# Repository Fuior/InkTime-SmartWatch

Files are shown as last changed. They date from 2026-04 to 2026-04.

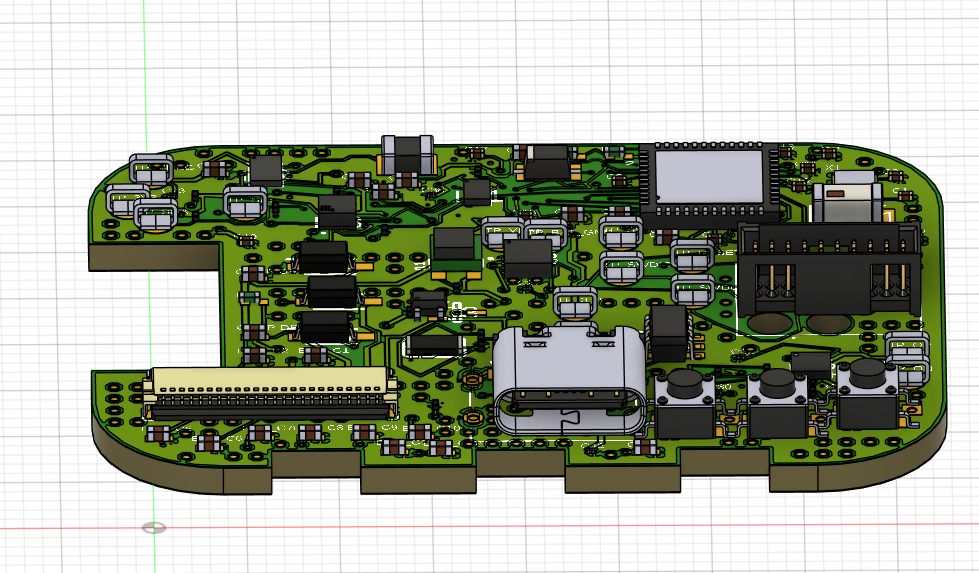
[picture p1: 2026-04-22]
Images/PCB_3D_Side_View.PNG

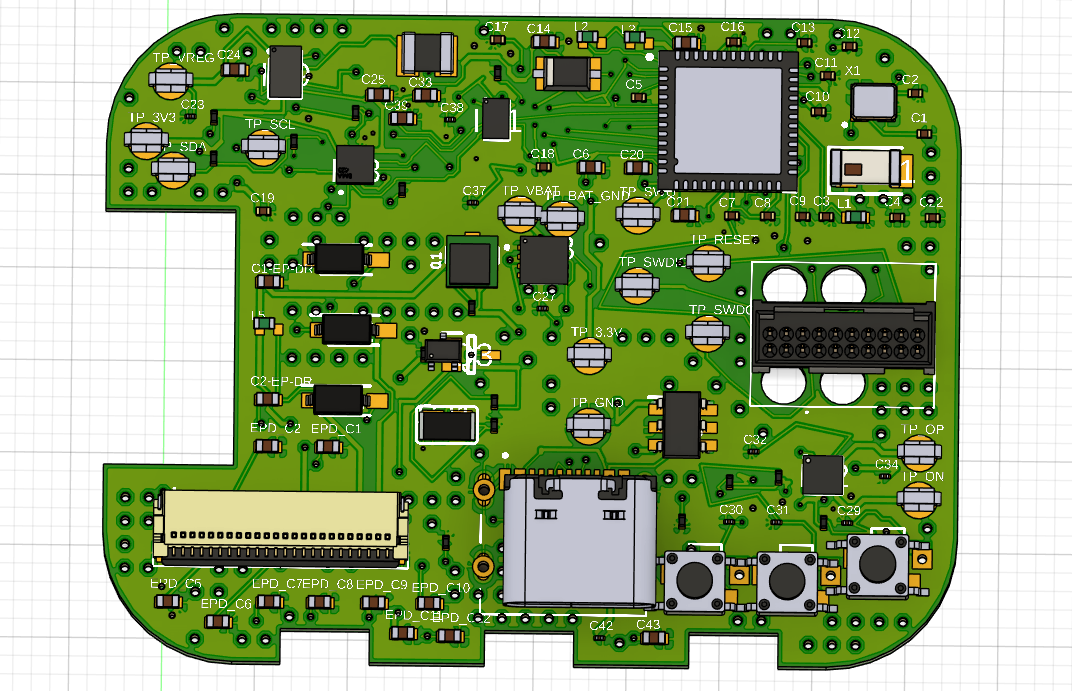
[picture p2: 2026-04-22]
Images/PCB_3D_Top_View.PNG

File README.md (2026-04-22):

# InkTime-SmartWatch

## Project Overview

InkTime-SmartWatch is a compact wearable embedded system built around the Nordic nRF52840 microcontroller, designed for ultra-low-power smartwatch applications using an e-paper display, motion sensing, haptic feedback, battery monitoring and USB-C charging.

The project integrates power management, sensing, display driving and wireless communication into a compact PCB optimized for enclosure integration.

---

# Block Diagram

```text
USB-C Input
   ↓
LiPo Charger
   ↓
LiPo Battery
   ↓
DC/DC Converter
   ↓
nRF52840 MCU
 ├── E-Paper Display (SPI)
 ├── IMU Sensor (I2C)
 ├── Fuel Gauge (I2C)
 ├── Haptic Driver (I2C / GPIO)
 ├── Buttons (GPIO Interrupts)
 ├── SWD Debug Interface
 └── BLE Antenna
```

---

# Bill of Materials (BOM)

| Component | Part | Function |
| --- | --- | --- |
| MCU | nRF52840-QFAA | Main microcontroller |
| Battery Charger | BQ25180 | LiPo charging |
| DC/DC Converter | RT6150 | Voltage regulation |
| IMU | Motion sensor | Accelerometer / motion sensing |
| Fuel Gauge | MAX17048 | Battery level measurement |
| Haptic Driver | DRV2605 | Vibration motor control |
| Display Connector | 24-pin FPC | E-paper connection |
| USB-C Connector | Type-C | Charging and power |
| ESD Protection | USBLC6 | USB protection |
| Buttons | Tactile switches | User input |
| SWD Header | TC2030 | Programming/debug |

---

# Hardware Functional Description

## Microcontroller Core

The central processing unit of the smartwatch is the Nordic nRF52840, a BLE-enabled ARM Cortex-M4 microcontroller selected for:

* low power consumption
* integrated Bluetooth Low Energy
* SPI / I2C / GPIO flexibility
* wearable device suitability

The MCU handles:

* display updates
* sensor acquisition
* battery monitoring
* haptic events
* user input

---

## Power Management

The power subsystem contains:

### LiPo Charger

BQ25180 charger manages battery charging through USB-C input.

Functions:

* battery charging
* input protection
* charging regulation

### DC/DC Converter

RT6150 converts battery voltage to regulated supply rails for MCU and peripherals.

Main outputs:

* 3.3V logic supply
* regulated peripheral rail

---

## Display Subsystem

The smartwatch uses an e-paper display interface.

Advantages:

* ultra low power
* persistent image retention
* sunlight readability

Dedicated E-Paper Driver section generates required voltages.

---

## IMU Sensor

The inertial measurement unit provides motion data:

* acceleration
* movement detection
* orientation sensing

Used for:

* wake-up events
* motion-based interface control

---

## Fuel Gauge

MAX17048 continuously measures battery charge state.

Functions:

* battery voltage monitoring
* charge estimation
* low battery alert

---

## Haptic Feedback

DRV2605 driver controls the vibration motor.

Allows:

* notifications
* tactile feedback
* programmable vibration patterns

---

## USB-C Interface

USB-C connector provides:

* charging input
* power delivery
* ESD protected connection

Protection implemented using USBLC6 device.

---

## Buttons

Three hardware buttons are implemented:

* SW_UP
* SW_INT
* SW_DN

Used for:

* navigation
* selection
* wake-up interrupt

---

# nRF52840 Pin Assignment

| nRF52840 Pin | Connected Module | Interface | Purpose |
| --- | --- | --- | --- |
| P0.13 | Display Clock | SPI | Display clock |
| P0.15 | Display Data | SPI | Display data  |
| P0.24 | Haptic control | GPIO | Motor trigger |
| P0.26 | IMU SDA | I2C | Sensor data |
| P0.27 | IMU SCL | I2C | Sensor clock  |
| P1.xx | Buttons | GPIO | User input |
| SWDIO | Debug | SWD | Programming |
| SWDCLK | Debug | SWD | Programming |

---

# Power Consumption Considerations

Estimated current consumption:

* MCU active: ~5 mA
* E-paper refresh: ~20 mA
* IMU active: ~1 mA
* Haptic pulse: ~80 mA

Battery sizing selected for wearable operation with optimized duty cycle.

---

# Mechanical Integration

The mechanical assembly contains:

* PCB
* LiPo battery
* e-paper display
* vibration motor
* enclosure

Placement order:

top to bottom:

Display → Battery → PCB → Case

---

# Design Decisions

Main design goals:

* compact PCB layout
* low power architecture
* short SPI lines to display
* antenna edge placement
* battery direct pad connection

---

# Rendered Images

Project folder contains:

* PCB 3D top render
* PCB 3D side render
* complete assembly top render
* complete assembly side render
* exploded mechanical view

---

# Files Included

## Hardware

* schematic (.sch)
* board (.brd)
* schematic PDF

## Manufacturing

* gerbers.zip
* BOM
* CPL

## Mechanical

* STEP exploded assembly
* STEP PCB 3D
* Fusion360 project

## Images

* PCB renders
* assembly renders

---

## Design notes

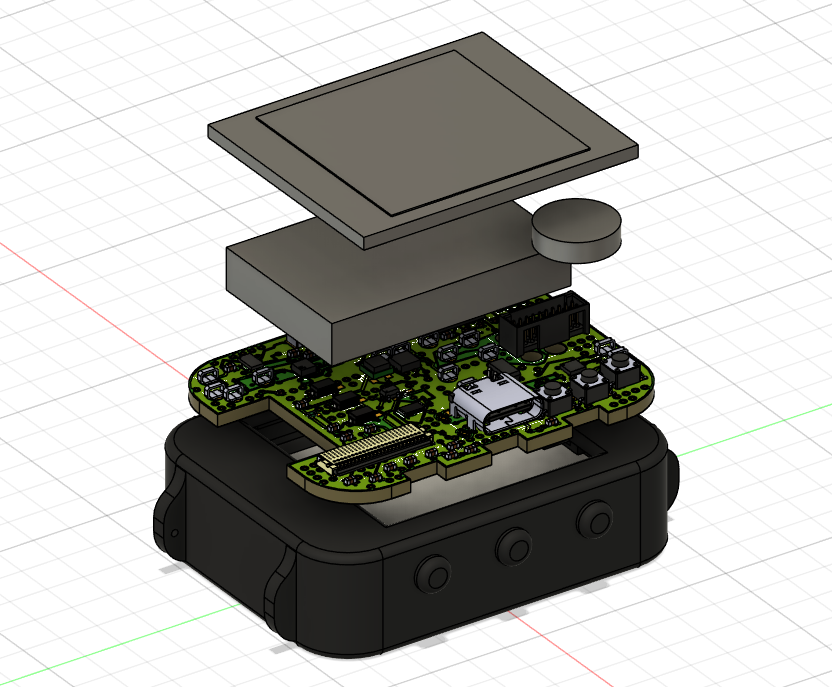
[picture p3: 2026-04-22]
Images/Device_Exploded_Side_View.PNG

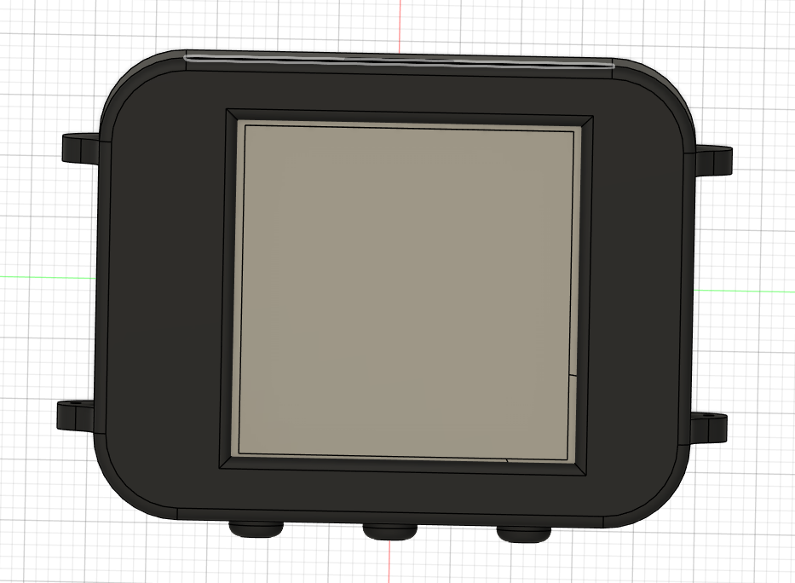
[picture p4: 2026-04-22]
Images/Device_Complete_Top_View.PNG

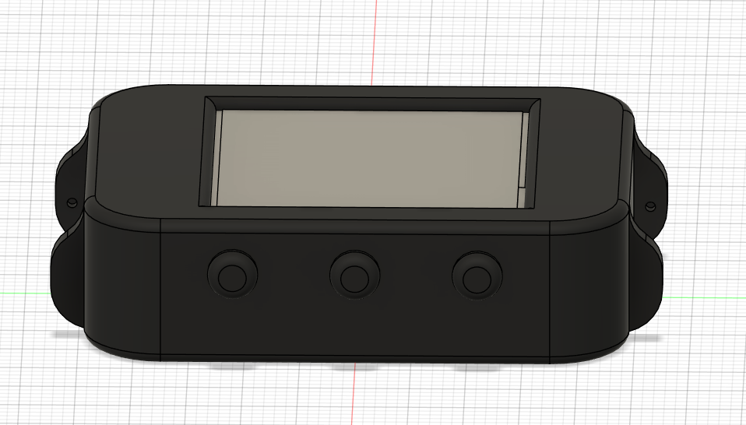
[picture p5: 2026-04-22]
Images/Device_Complete_Side_View.PNG

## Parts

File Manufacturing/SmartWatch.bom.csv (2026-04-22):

Reference Designators | Quantity | Description | Package | Value | Manufacturer | Manufacturer Part Number | Vendor | Vendor Part Number | Top/Bottom
 | 1 | Board | Board
ANT1 | 1 | Antennas 2.45GHz ANTENNA | 2450AT18B100E_ANTC3216X140N | 2450AT18B100E |  |  |  |  | Top
C1, C2, C17, C18 | 4 | Generic chip capacitor | NORDIC_NRF_3_RESC0201_L | 12pF |  |  |  |  | Top
C1-EP-DR, C24, C39 | 3 | Generic chip capacitor | NORDIC_NRF_3_RESC0402_L | 10uF |  |  |  |  | Top
C2-EP-DR | 1 | Generic chip capacitor | NORDIC_NRF_3_RESC0402_L | 4.7uF/25V |  |  |  |  | Top
C3, C4 | 2 | Generic chip capacitor | NORDIC_NRF_3_RESC0201_L | 1pF |  |  |  |  | Top
C5, C7, C8, C12, C19 | 5 | Generic chip capacitor | NORDIC_NRF_3_RESC0201_L | 100nF |  |  |  |  | Top
C6, C14, C20, C21 | 4 | Generic chip capacitor | NORDIC_NRF_3_RESC0402_L | 4.7μF |  |  |  |  | Top
C9 | 1 | Generic chip capacitor | NORDIC_NRF_3_RESC0201_L | 820pF |  |  |  |  | Top
C10, C13, C22 | 3 | Generic chip capacitor | NORDIC_NRF_3_RESC0201_L | N.C. |  |  |  |  | Top
C11 | 1 | Generic chip capacitor | NORDIC_NRF_3_RESC0201_L | 100pF |  |  |  |  | Top
C15 | 1 | Generic chip capacitor | NORDIC_NRF_3_RESC0402_L | 1.0μF |  |  |  |  | Top
C16 | 1 | Generic chip capacitor | NORDIC_NRF_3_RESC0201_L | 47nF |  |  |  |  | Top
C23, C27, C34, C42 | 4 | Check availability | CAPC0201X13N | 0.1uF |  |  |  |  | Top
C25, C33 | 2 | Generic chip capacitor | NORDIC_NRF_3_RESC0402_L | 22uF |  |  |  |  | Top
C29, C30, C31, C32, C37, C38 | 6 | Check availability | CAPC0201X13N | 1uF |  |  |  |  | Top
C43 | 1 | Generic chip capacitor | NORDIC_NRF_3_RESC0402_L | 4.7uF |  |  |  |  | Top
D2, D4, D5 | 3 | ON SEMICONDUCTOR - MBR0530 - DIODE, SCHOTTKY, 0.5A, 30V, SOD-123 | SOD3716X135N | MBR0530 |  |  |  |  | Top
D3 | 1 | Low Cap. ESD Protection Auto SOT-23-6 STMicroelectronics USBLC6-2SC6Y, Dual Uni-Directional TVS Diode Array, 6-Pin SOT-23 | SOT95P280X145-6N | USBLC6-2SC6Y |  |  |  |  | Top
EPD_C1, EPD_C2, EPD_C6, EPD_C7, EPD_C8, EPD_C9, EPD_C10, EPD_C11, EPD_C12 | 9 | Generic chip capacitor | NORDIC_NRF_3_RESC0402_L | 1uF/50V |  |  |  |  | Top
EPD_C5 | 1 | Generic chip capacitor | NORDIC_NRF_3_RESC0402_L | 0.1uF/50V |  |  |  |  | Top
IC1 | 1 | Charger IC Lithium Ion/Polymer, Lithium Iron Phosphate 8-DSBGA (1.6x1.1) | BQ25180YBGR_BGA8C40P2X4_100X155X50 | BQ25180YBGR |  |  |  |  | Top
IC2 | 1 | Haptic Driver for ERM/LRA with Built-In Library and Smart Loop Architecture | DRV2605YZFR_BGA9C50P3X3_144X144X62 | DRV2605YZFR |  |  |  |  | Top
IC3 | 1 | Accelerometers Triaxial low-g 12bit Acceleration Sensor | BMA423_BMA423 | BMA423 |  |  |  |  | Top
IC9 | 1 | Buck-Boost Regulator Positive Output Step-Up/Step-Down I2C DC-DC Controller IC 15-WL-CSP (BSC) (1.4x2.3) | RT6160AWSC_BGA15C40P3X5_140X230X60 | RT6160AWSC |  |  |  |  | Top
J1 | 1 | FFC & FPC Connectors 0.5mm FPC RA SMT Dual Contact 24Ckt | 503480-2400_5034802400 | 503480-2400 |  |  |  |  | Top
J2 | 1 | CABLE ADAPTER 6 POS | TC2030-IDC_TC2030IDC | TC2030-IDC |  |  |  |  | Top
J4 | 1 | Check availability | KINGHELM_KH-TYPE-C-16P | KH-TYPE-C-16P |  |  |  |  | Top
L1 | 1 | Generic chip inductor | NORDIC_NRF_2_RESC0402_L | 3.9nH |  |  |  |  | Top
L2 | 1 | Generic chip inductor | NORDIC_NRF_2_RESC0402_L | 10μH |  |  |  |  | Top
L3 | 1 | Generic chip inductor | NORDIC_NRF_2_RESC0402_L | 15nH |  |  |  |  | Top
L5 | 1 | Generic chip inductor | NORDIC_NRF_2_RESC0402_L | 68uH |  |  |  |  | Top
L7 | 1 | SMD / SMT Inductors (Coils), L=0.47?H, L x W x T : | MLP2016SR47MT0S1_INDC2016X100N | FTC252012SR47MBCA |  |  |  |  | Top
Q1 | 1 | P-channel MOSFETs | ESP32_WROVER_SPARKFUN-DISCRETESEMI_SOT23-3 | 20V/4.2A/52mΩ/1.4W |  |  |  |  | Top
Q3 | 1 | MOSFET N-Ch 30V 1.5A TrenchFET SC70 Vishay Si1308EDL-T1-GE3 N-channel MOSFET Transistor, 1.5 A, 30 V, 3-Pin SC-70 | SOT65P210X110-3N | SI1308EDL-T1-GE3 |  |  |  |  | Top
R_PWR_EPD, R5, R7, R8 | 4 | 7.68k 0201 Thin Film Surface Mount Fixed Resistor +/-0.5% 0.031W CPF0201D7K68C1 | CPF0201D7K68C1_0201 | 10K |  |  |  |  | Top
R_TYPE_SEL | 1 | 7.68k 0201 Thin Film Surface Mount Fixed Resistor +/-0.5% 0.031W CPF0201D7K68C1 | CPF0201D7K68C1_0201 | 2.2 |  |  |  |  | Top
R1_EP_DR | 1 | 7.68k 0201 Thin Film Surface Mount Fixed Resistor +/-0.5% 0.031W CPF0201D7K68C1 | CPF0201D7K68C1_0201 | 0.47 |  |  |  |  | Top
R1_USB, R2_USB | 2 | 7.68k 0201 Thin Film Surface Mount Fixed Resistor +/-0.5% 0.031W CPF0201D7K68C1 | CPF0201D7K68C1_0201 | 5K1 |  |  |  |  | Top
R2, R4 | 2 | 7.68k 0201 Thin Film Surface Mount Fixed Resistor +/-0.5% 0.031W CPF0201D7K68C1 | CPF0201D7K68C1_0201 | 0 |  |  |  |  | Top
R2_EP_DR, R9 | 2 | 7.68k 0201 Thin Film Surface Mount Fixed Resistor +/-0.5% 0.031W CPF0201D7K68C1 | CPF0201D7K68C1_0201 | 10K |  |  |  |  | Top
R3 | 1 | 7.68k 0201 Thin Film Surface Mount Fixed Resistor +/-0.5% 0.031W CPF0201D7K68C1 | CPF0201D7K68C1_0201 | 0 |  |  |  |  | Top
R17, R18 | 2 | 7.68k 0201 Thin Film Surface Mount Fixed Resistor +/-0.5% 0.031W CPF0201D7K68C1 | CPF0201D7K68C1_0201 | 3K3 |  |  |  |  | Top
SJ1 | 1 | SMD solder JUMPER | JUMPER_SJ |  |  |  |  |  | Top
SW_DN, SW_ENT, SW_UP | 3 |  | SW_EVP-AKE31A_PAN | 2025-10-22_07-23-44_LIBRARY_EVP-AKE31ASW_EVP-AKE31A_PAN |  |  |  |  | Top
TP_3.3V, TP_3V3, TP_BAT_GND, TP_GND, TP_ON, TP_OP, TP_RESET, TP_SCL, TP_SDA, TP_SWDCLK, TP_SWDIO, TP_SWO, TP_VBAT, TP_VREG | 14 | Test pad | HECTOR_WATCH_1_TP20R | HECTOR_WATCH_1_TPTP20R |  |  |  |  | Top
U$1 | 1 | nRF52840 | NORDIC_NRF_4_AQFN50P700X700X85_HS-74N | NRF52840_QF |  |  |  |  | Top
U3 | 1 | Check availability | SON50P200X200X80-9N | MAX17048G+T10 |  |  |  |  | Top
X1 | 1 |  | NORDIC_NRF_BT-XTAL_2016_N | 32MHz |  |  |  |  | Top
X2 | 1 |  | NORDIC_NRF_1_XTAL_3215_N | 32.768kHz |  |  |  |  | Top

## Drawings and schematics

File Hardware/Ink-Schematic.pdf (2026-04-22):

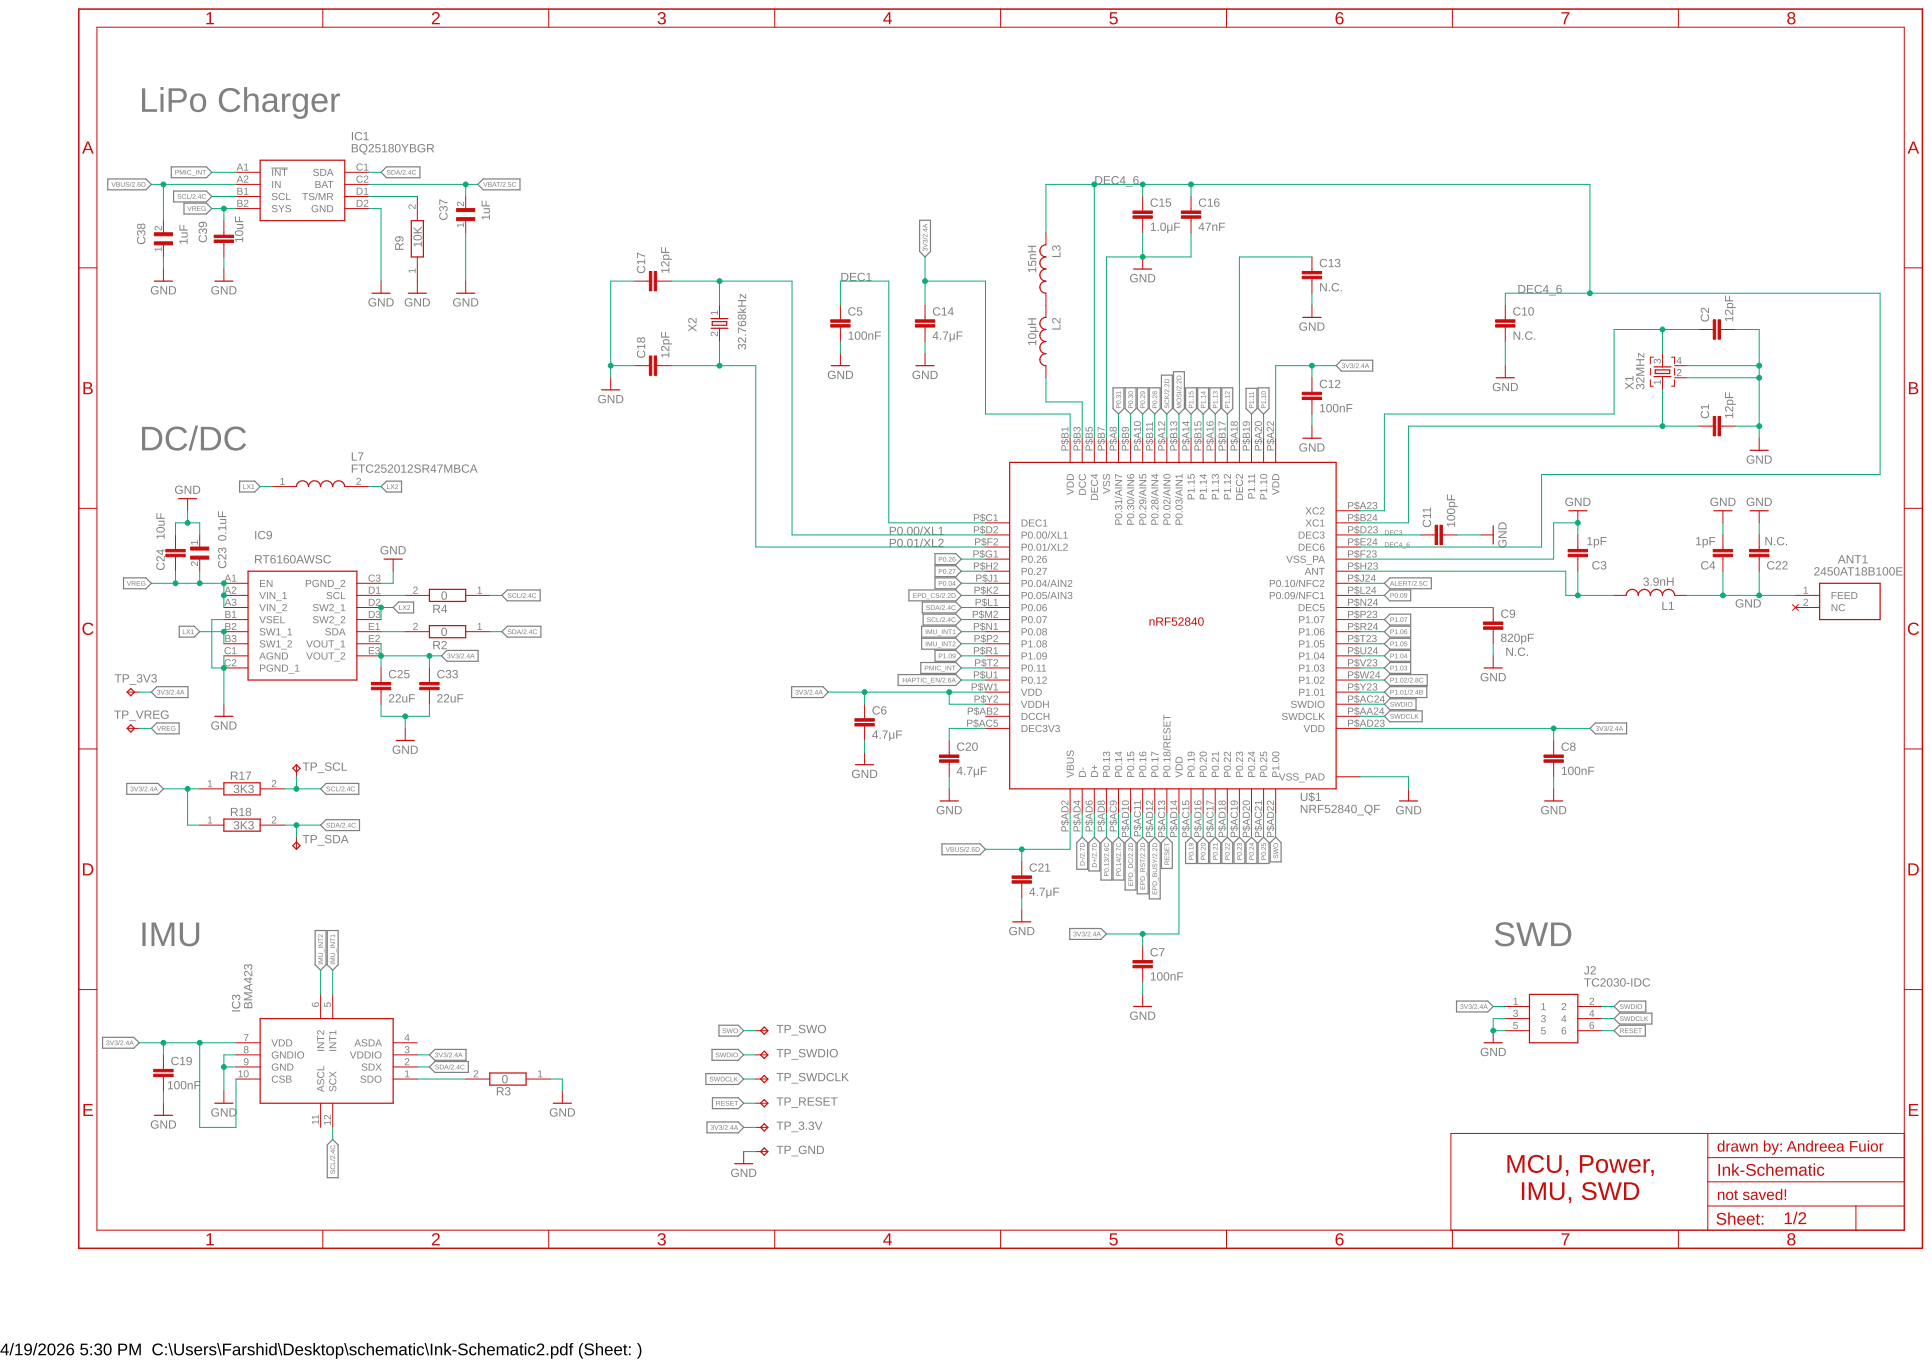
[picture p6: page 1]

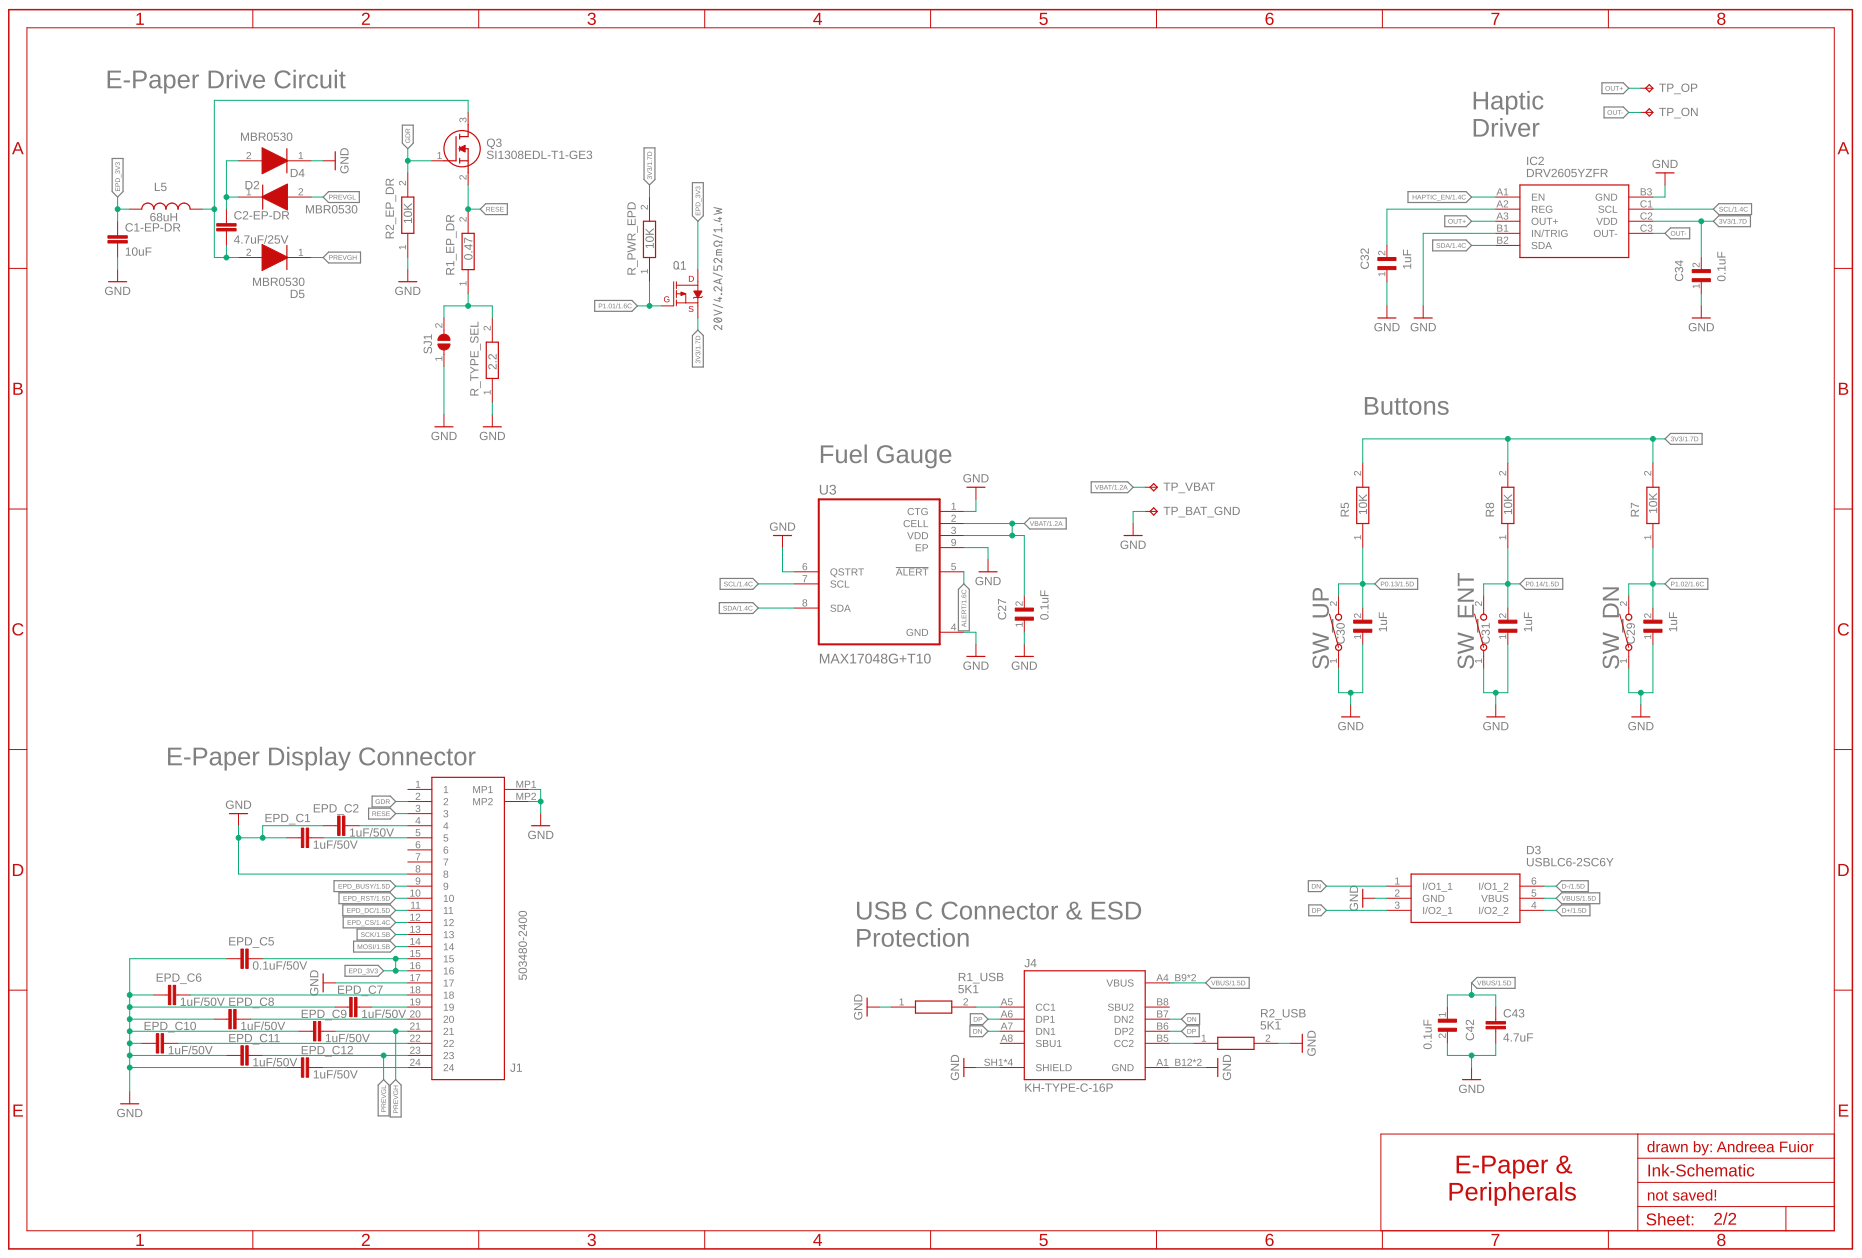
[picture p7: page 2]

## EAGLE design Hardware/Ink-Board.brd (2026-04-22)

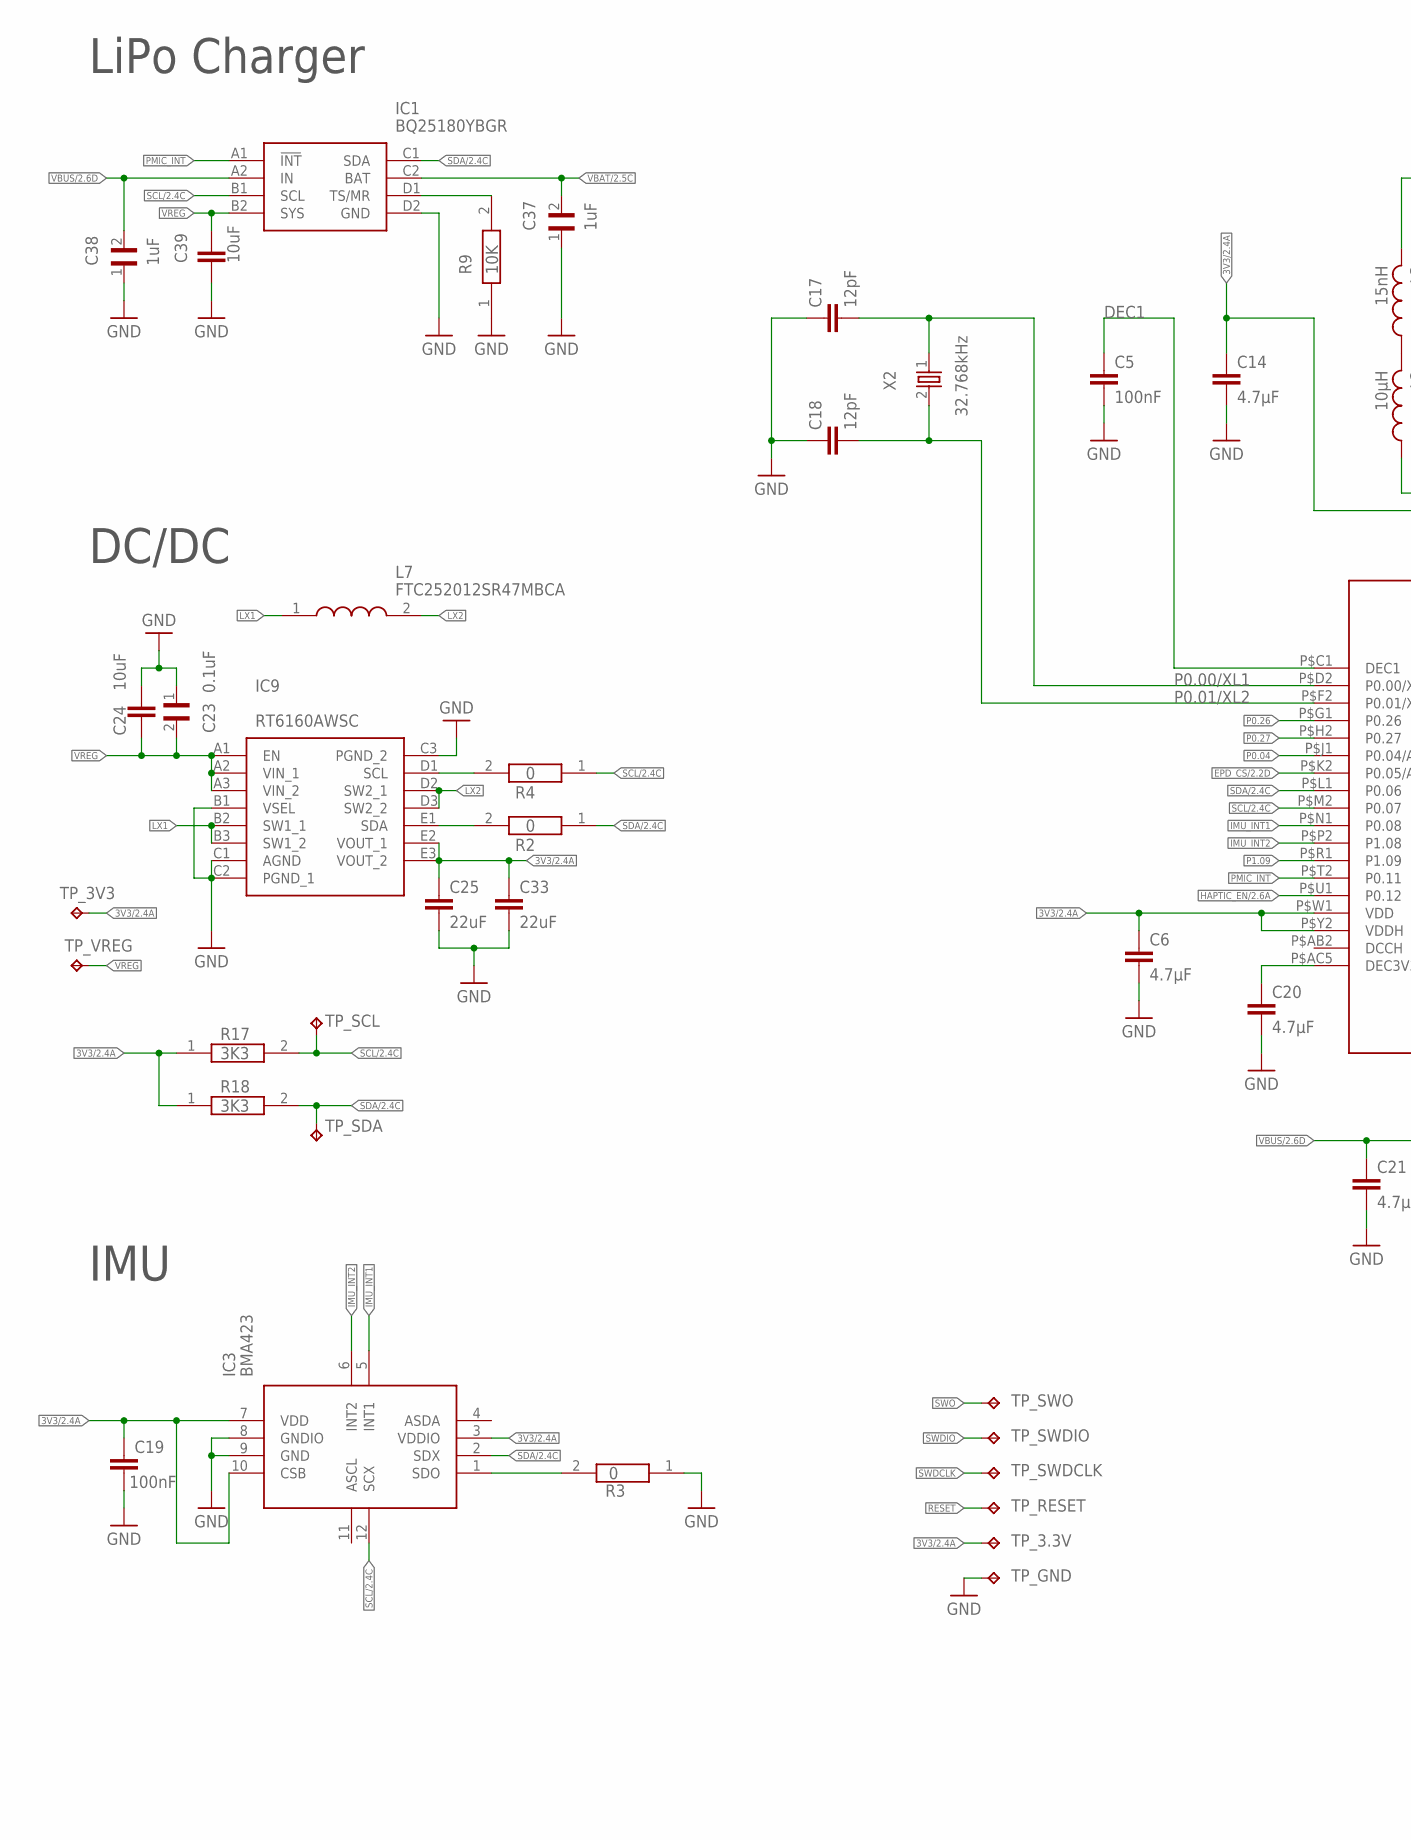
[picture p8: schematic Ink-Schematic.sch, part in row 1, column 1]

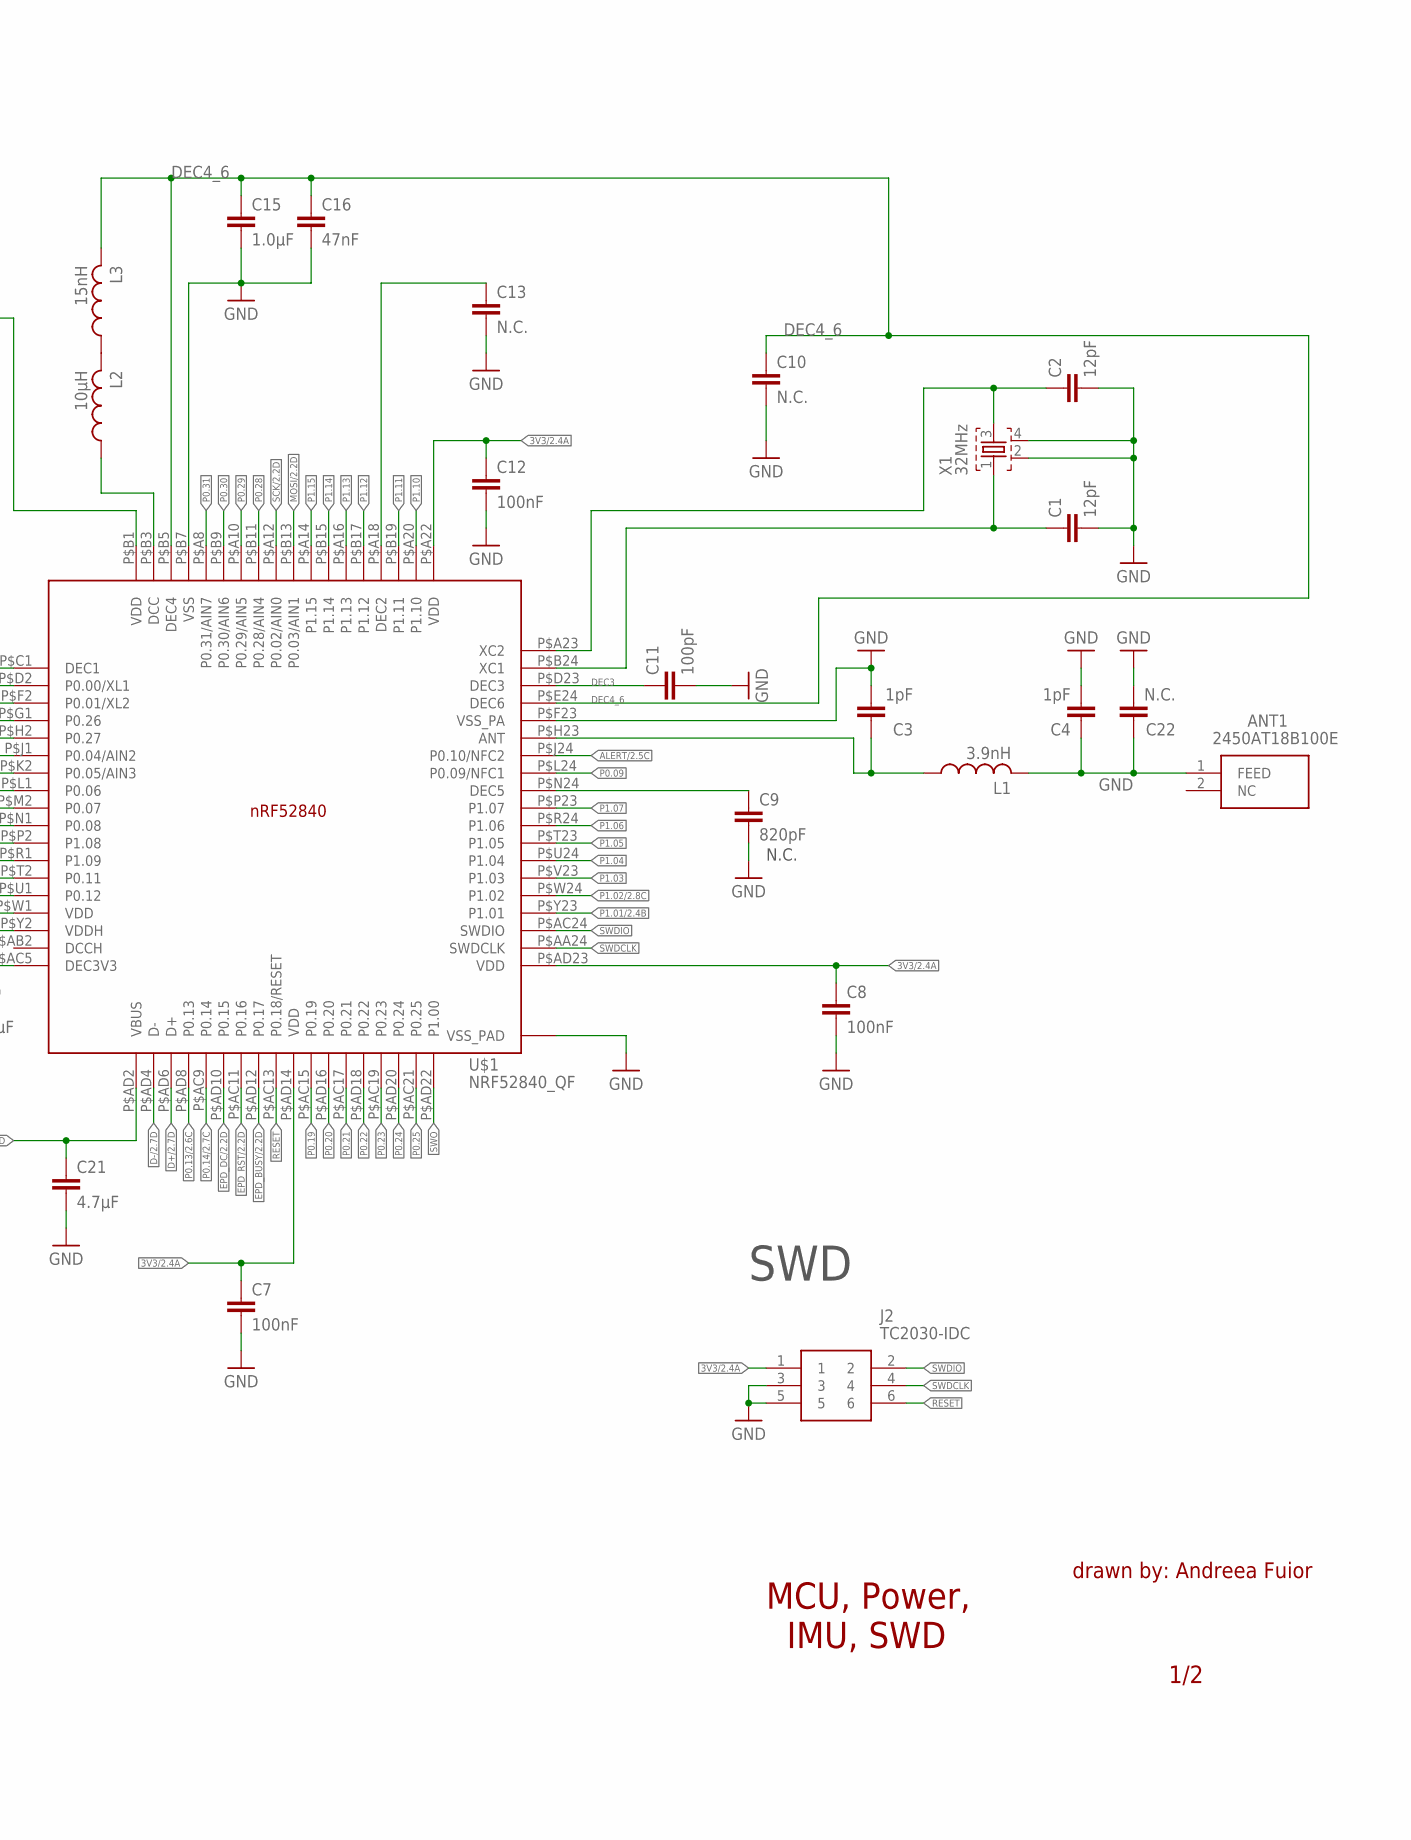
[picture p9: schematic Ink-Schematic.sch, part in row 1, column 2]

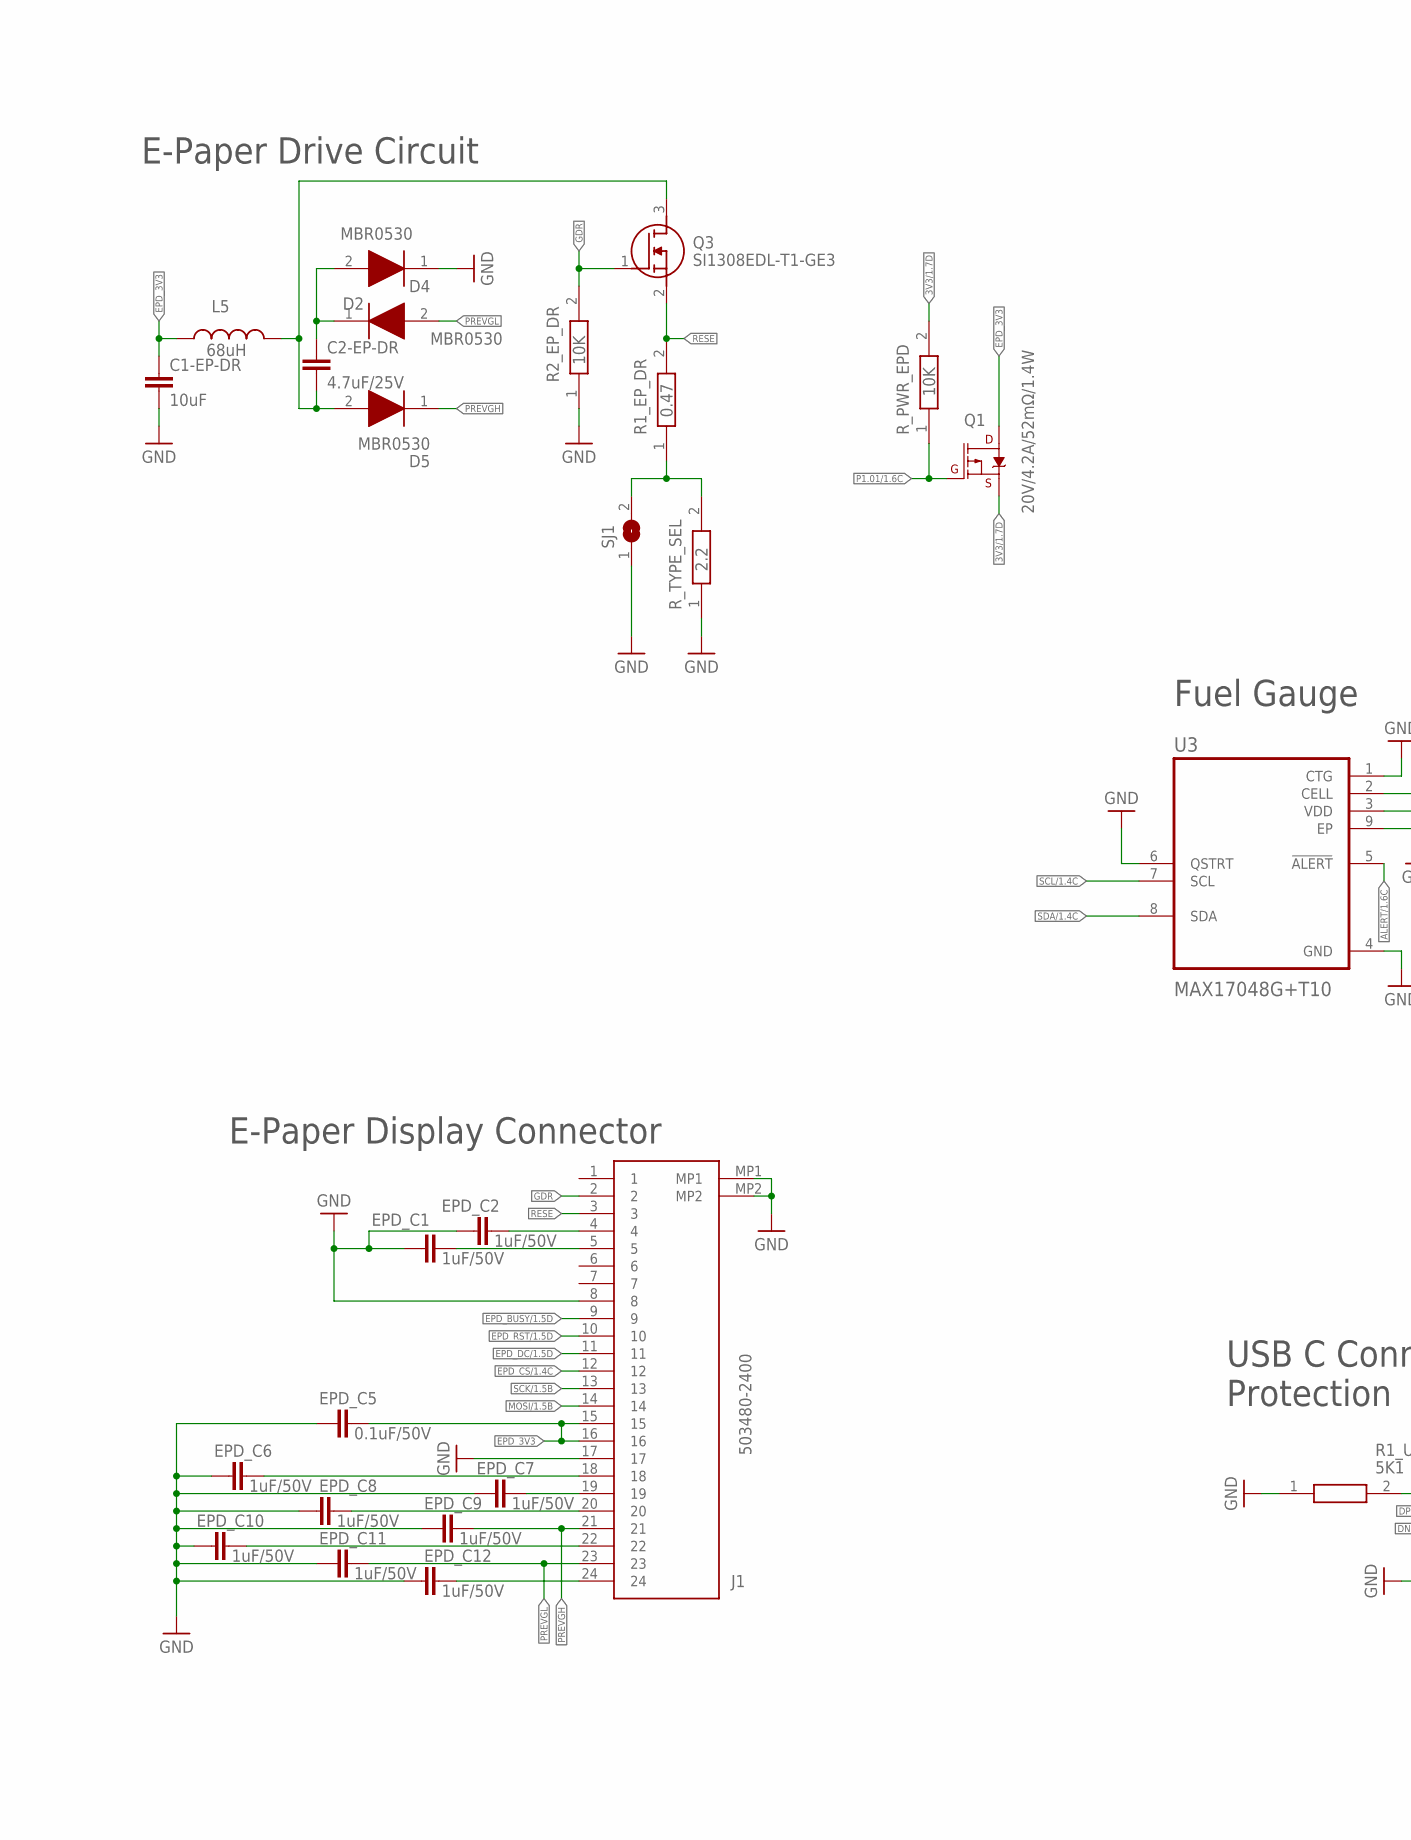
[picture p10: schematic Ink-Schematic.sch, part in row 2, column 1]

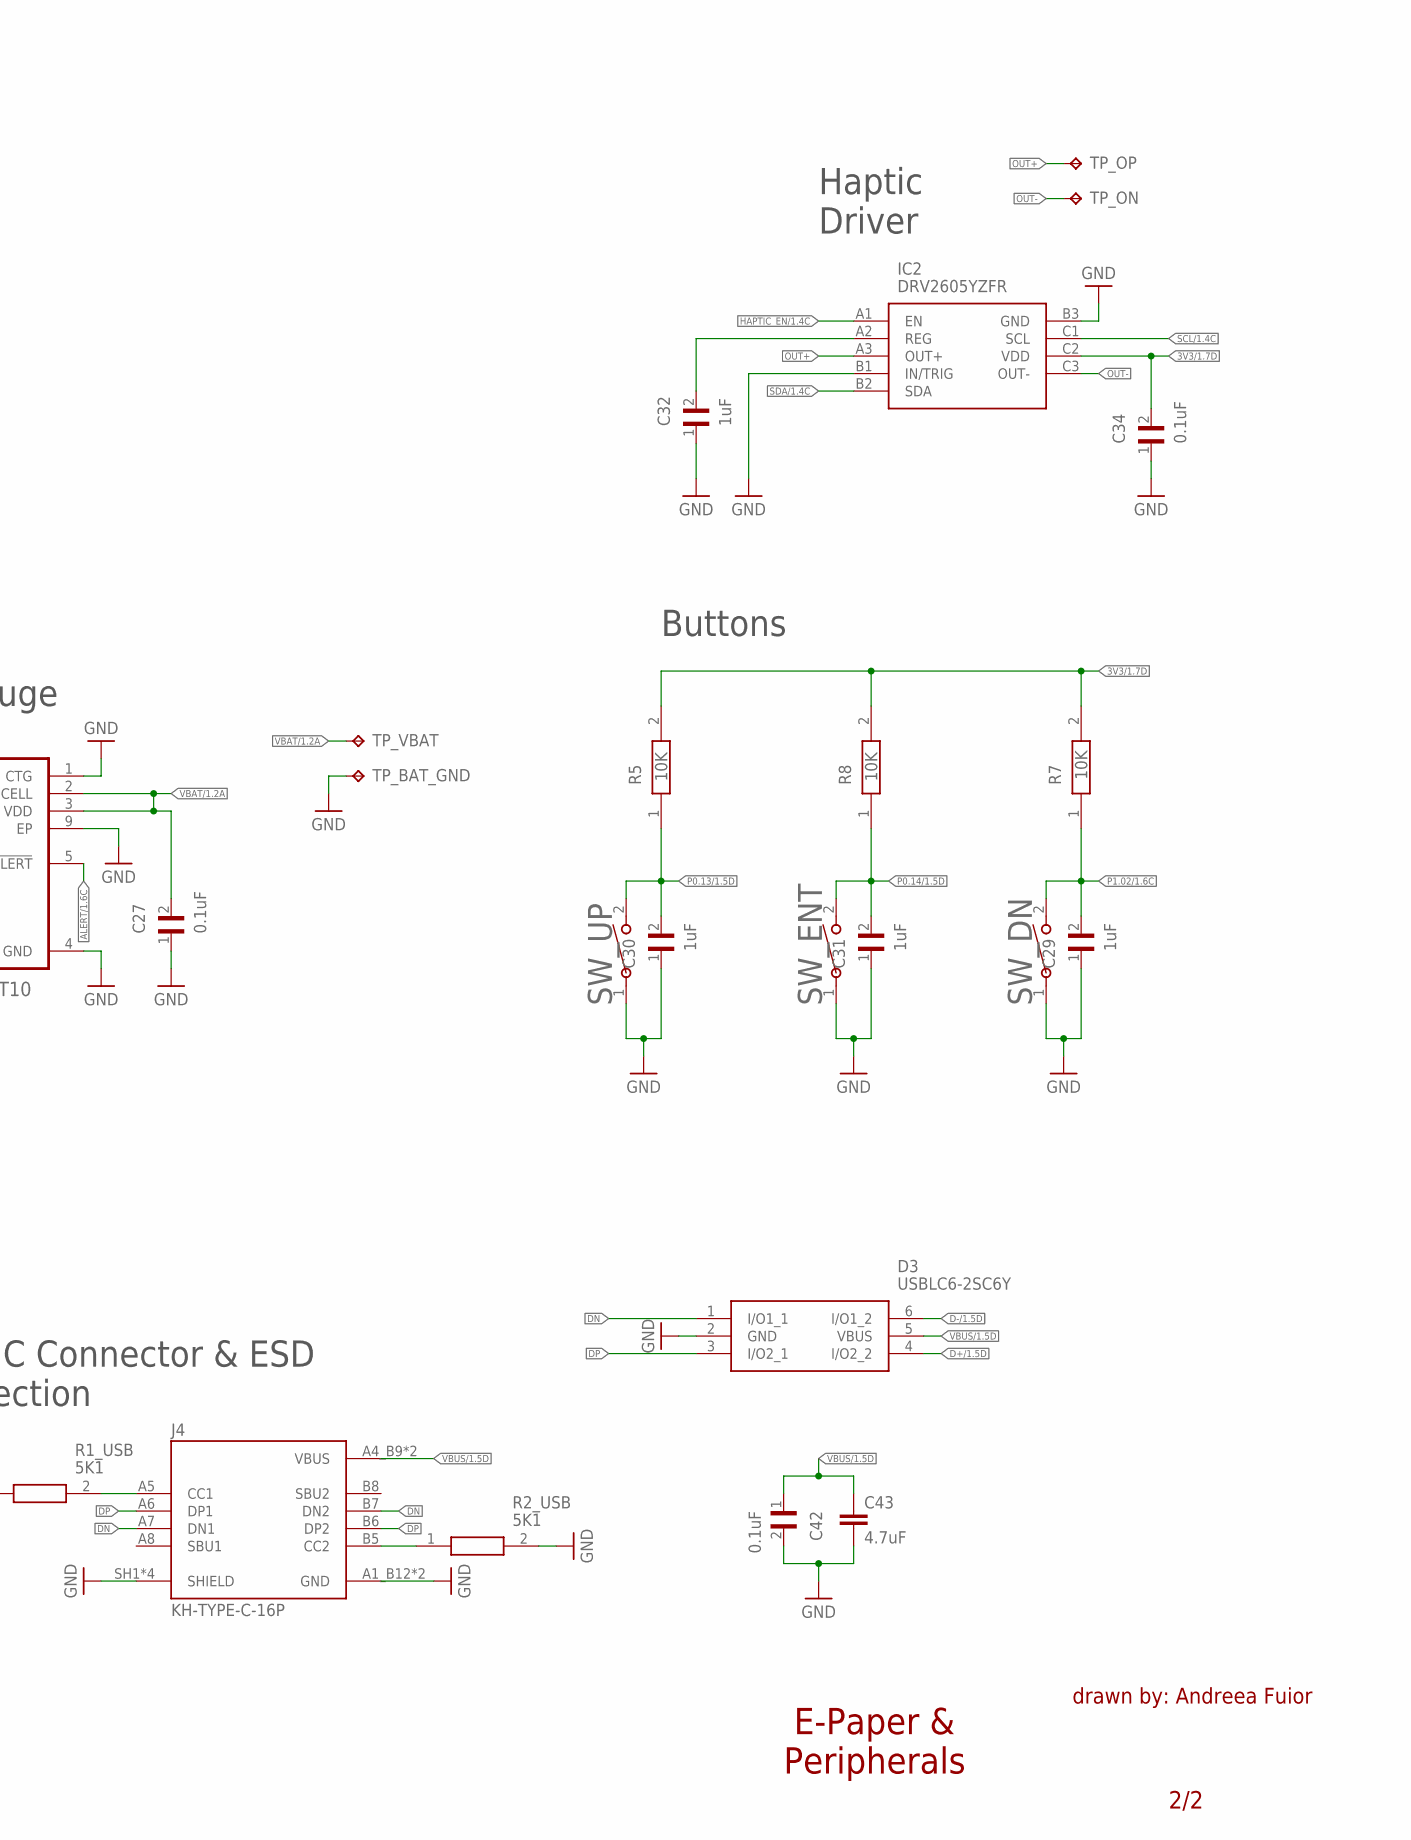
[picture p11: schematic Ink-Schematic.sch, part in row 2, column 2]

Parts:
ANT1: 2450AT18B100E; 2450AT18B100E_ANTC3216X140N
C1, C2, C17, C18: 12pF; NORDIC_NRF_3_RESC0201_L
C1-EP-DR, C24, C39: 10uF; NORDIC_NRF_3_RESC0402_L
C2-EP-DR: 4.7uF/25V; NORDIC_NRF_3_RESC0402_L
C3, C4: 1pF; NORDIC_NRF_3_RESC0201_L
C5, C7, C8, C12, C19: 100nF; NORDIC_NRF_3_RESC0201_L
C6, C14, C20, C21: 4.7μF; NORDIC_NRF_3_RESC0402_L
C9: 820pF; NORDIC_NRF_3_RESC0201_L
C10, C13, C22: N.C.; NORDIC_NRF_3_RESC0201_L
C11: 100pF; NORDIC_NRF_3_RESC0201_L
C15: 1.0μF; NORDIC_NRF_3_RESC0402_L
C16: 47nF; NORDIC_NRF_3_RESC0201_L
C23, C27, C34, C42: 0.1uF; GRM011R60J152KE01L_2_CAPC0201X13N
C25, C33: 22uF; NORDIC_NRF_3_RESC0402_L
C29, C30, C31, C32, C37, C38: 1uF; GRM011R60J152KE01L_2_CAPC0201X13N
C43: 4.7uF; NORDIC_NRF_3_RESC0402_L
D2, D4, D5: MBR0530; ESP32_C6_LIBRARY_5_SOD3716X135N
D3: USBLC6-2SC6Y; ESP32_C6_LIBRARY_3_SOT95P280X145-6N
EPD_C1, EPD_C2, EPD_C6, EPD_C7, EPD_C8, EPD_C9, EPD_C10, EPD_C11, EPD_C12: 1uF/50V; NORDIC_NRF_3_RESC0402_L
EPD_C5: 0.1uF/50V; NORDIC_NRF_3_RESC0402_L
IC1: BQ25180YBGR; BQ25180YBGR_BGA8C40P2X4_100X155X50
IC2: DRV2605YZFR; DRV2605YZFR_BGA9C50P3X3_144X144X62
IC3: BMA423; BMA423_BMA423
IC9: RT6160AWSC; RT6160AWSC_BGA15C40P3X5_140X230X60
J1: 503480-2400; 503480-2400_5034802400
J2: TC2030-IDC; TC2030-IDC_TC2030IDC
J4: KH-TYPE-C-16P; KH-TYPE-C-16P_KINGHELM_KH-TYPE-C-16P
L1: 3.9nH; NORDIC_NRF_2_RESC0402_L
L2: 10μH; NORDIC_NRF_2_RESC0402_L
L3: 15nH; NORDIC_NRF_2_RESC0402_L
L5: 68uH; NORDIC_NRF_2_RESC0402_L
L7: FTC252012SR47MBCA; MLP2016SR47MT0S1_INDC2016X100N
Q1: 20V/4.2A/52mΩ/1.4W; ESP32_C6_LIBRARY_4_ESP32_C6_LIBRARY_4_ESP32_C6_LIBRARY_4_ES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
Q3: SI1308EDL-T1-GE3; ESP32_C6_LIBRARY_6_SOT65P210X110-3N
R1_EP_DR: 0.47; CPF0201D7K68C1_0201
R1_USB, R2_USB: 5K1; CPF0201D7K68C1_0201
R2, R3, R4: 0; CPF0201D7K68C1_0201
R2_EP_DR, R5, R7, R8, R9: 10K; CPF0201D7K68C1_0201
R17, R18: 3K3; CPF0201D7K68C1_0201
R_PWR_EPD: 10K; CPF0201D7K68C1_0201
R_TYPE_SEL: 2.2; CPF0201D7K68C1_0201
SJ1: ESP32_C6_LIBRARY_7_JUMPER_SJ
SW_DN: 2025-10-22_07-23-44_LIBRARY_EVP-AKE31ASW_EVP-AKE3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; 2025-10-22_07-23-44_LIBRARY_SW_EVP-AKE31A_PAN
SW_ENT: 2025-10-22_07-23-44_LIBRARY_EVP-AKE31ASW_EVP-AKE3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; 2025-10-22_07-23-44_LIBRARY_SW_EVP-AKE31A_PAN
SW_UP: 2025-10-22_07-23-44_LIBRARY_EVP-AKE31ASW_EVP-AKE3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; 2025-10-22_07-23-44_LIBRARY_SW_EVP-AKE31A_PAN
TP_3.3V, TP_3V3: HECTOR_WATCH_1_TPTP20R; HECTOR_WATCH_1_TP20R
TP_BAT_GND: HECTOR_WATCH_1_TPTP20R; HECTOR_WATCH_1_TP20R
TP_GND: HECTOR_WATCH_1_TPTP20R; HECTOR_WATCH_1_TP20R
TP_ON: HECTOR_WATCH_1_TPTP20R; HECTOR_WATCH_1_TP20R
TP_OP: HECTOR_WATCH_1_TPTP20R; HECTOR_WATCH_1_TP20R
TP_RESET: HECTOR_WATCH_1_TPTP20R; HECTOR_WATCH_1_TP20R
TP_SCL: HECTOR_WATCH_1_TPTP20R; HECTOR_WATCH_1_TP20R
TP_SDA: HECTOR_WATCH_1_TPTP20R; HECTOR_WATCH_1_TP20R
TP_SWDCLK: HECTOR_WATCH_1_TPTP20R; HECTOR_WATCH_1_TP20R
TP_SWDIO: HECTOR_WATCH_1_TPTP20R; HECTOR_WATCH_1_TP20R
TP_SWO: HECTOR_WATCH_1_TPTP20R; HECTOR_WATCH_1_TP20R
TP_VBAT: HECTOR_WATCH_1_TPTP20R; HECTOR_WATCH_1_TP20R
TP_VREG: HECTOR_WATCH_1_TPTP20R; HECTOR_WATCH_1_TP20R
U3: MAX17048G+T10; ESP32_C6_LIBRARY_SON50P200X200X80-9N
U$1: NRF52840_QF; NORDIC_NRF_4_AQFN50P700X700X85_HS-74N
X1: 32MHz; NORDIC_NRF_BT-XTAL_2016_N
X2: 32.768kHz; NORDIC_NRF_1_XTAL_3215_N

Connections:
3V3/1.7D: C34.2, IC2.C2 (VDD), Q1.2 (S), R5.2, R7.2, R8.2, R_PWR_EPD.2
3V3/2.4A: C6.1, C7.1, C8.1, C12.1, C14.1, C19.1, C25.1, C33.1, IC3.3 (VDDIO), IC3.7 (VDD), IC3.10 (CSB), IC9.E2 (VOUT_1), IC9.E3 (VOUT_2), J2.1, R17.1, R18.1, TP_3.3V.TP, TP_3V3.TP, U$1.P$A22 (VDD), U$1.P$AD14 (VDD), U$1.P$AD23 (VDD), U$1.P$B1 (VDD), U$1.P$W1 (VDD), U$1.P$Y2 (VDDH)
ALERT/1.6C: U3.5 (!ALERT)
ALERT/2.5C: U$1.P$J24 (P0.10/NFC2)
D+/1.5D: D3.4 (I/O2_2)
D+/2.7D: U$1.P$AD6 (D+)
D-/1.5D: D3.6 (I/O1_2)
D-/2.7D: U$1.P$AD4 (D-)
DEC1: C5.1, U$1.P$C1 (DEC1)
DEC3: C11.1, U$1.P$D23 (DEC3)
DEC4_6: C10.1, C15.1, C16.1, L3.2, U$1.P$B5 (DEC4), U$1.P$E24 (DEC6)
DN: D3.1 (I/O1_1), J4.A7 (DN1), J4.B7 (DN2)
DP: D3.3 (I/O2_1), J4.A6 (DP1), J4.B6 (DP2)
EPD_3V3: C1-EP-DR.1, EPD_C5.1, J1.15, J1.16, L5.1, Q1.3 (D)
EPD_BUSY/1.5D: J1.9
EPD_BUSY/2.2D: U$1.P$AD12 (P0.17)
EPD_CS/1.4C: J1.12
EPD_CS/2.2D: U$1.P$K2 (P0.05/AIN3)
EPD_DC/1.5D: J1.11
EPD_DC/2.2D: U$1.P$AD10 (P0.15)
EPD_RST/1.5D: J1.10
EPD_RST/2.2D: U$1.P$AC11 (P0.16)
GDR: J1.2, Q3.1 (G), R2_EP_DR.2
GND: ANT1.1 (FEED), C1.2, C1-EP-DR.2, C2.2, C3.2, C4.1, C4.2, C5.2, C6.2, C7.2, C8.2, C9.2, C10.2, C11.2, C12.2, C13.2, C14.2, C15.2, C16.2, C17.1, C18.1, C19.2, C20.2, C21.2, C22.1, C22.2, C23.1, C24.2, C25.2, C27.1, C29.1, C30.1, C31.1, C32.1, C33.2, C34.1, C37.1, C38.1, C39.2, C42.2, C43.2, D3.2 (GND), D4.1 (K), EPD_C1.2, EPD_C2.2, EPD_C5.2, EPD_C6.2, EPD_C7.2, EPD_C8.2, EPD_C9.2, EPD_C10.2, EPD_C11.2, EPD_C12.2, IC1.D2 (GND), IC2.B1 (IN/TRIG), IC2.B3 (GND), IC3.8 (GNDIO), IC3.9 (GND), IC9.B1 (VSEL), IC9.C1 (AGND), IC9.C2 (PGND_1), IC9.C3 (PGND_2), J1.8, J1.17, J1.MP1, J1.MP2, J2.3, J2.5, J4.A1_B12 (GND), J4.A12_B1 (GND), J4.SH1 (SHIELD), J4.SH2 (SHIELD), J4.SH3 (SHIELD), J4.SH4 (SHIELD), L1.2, R1_USB.1, R2_EP_DR.1, R2_USB.2, R3.1, R9.1, R_TYPE_SEL.1, SJ1.1, SW_DN.1, SW_ENT.1, SW_UP.1, TP_BAT_GND.TP, TP_GND.TP, U3.1 (CTG), U3.4 (GND), U3.6 (QSTRT), U3.9 (EP), U$1.P$74 (VSS_PAD), U$1.P$75 (VSS_PAD), U$1.P$76 (VSS_PAD), U$1.P$77 (VSS_PAD), U$1.P$78 (VSS_PAD), U$1.P$79 (VSS_PAD), U$1.P$80 (VSS_PAD), U$1.P$81 (VSS_PAD), U$1.P$82 (VSS_PAD), U$1.P$83 (VSS_PAD), U$1.P$84 (VSS_PAD), U$1.P$85 (VSS_PAD), U$1.P$86 (VSS_PAD), U$1.P$87 (VSS_PAD), U$1.P$88 (VSS_PAD), U$1.P$89 (VSS_PAD), U$1.P$90 (VSS_PAD), U$1.P$B7 (VSS), U$1.P$F23 (VSS_PA), X1.2, X1.4
HAPTIC_EN/1.4C: IC2.A1 (EN)
HAPTIC_EN/2.6A: U$1.P$U1 (P0.12)
IMU_INT1: IC3.5 (INT1), U$1.P$N1 (P0.08)
IMU_INT2: IC3.6 (INT2), U$1.P$P2 (P1.08)
LX1: IC9.B2 (SW1_1), IC9.B3 (SW1_2), L7.1
LX2: IC9.D2 (SW2_1), IC9.D3 (SW2_2), L7.2
MOSI/1.5B: J1.14
MOSI/2.2D: U$1.P$B13 (P0.03/AIN1)
unnamed: C9.1, U$1.P$N24 (DEC5)
unnamed: C3.1, L1.1, U$1.P$H23 (ANT)
unnamed: C1.1, U$1.P$B24 (XC1), X1.1
unnamed: C2.1, U$1.P$A23 (XC2), X1.3
unnamed: C13.1, U$1.P$A18 (DEC2)
unnamed: L2.1, U$1.P$B3 (DCC)
unnamed: L2.2, L3.1
unnamed: C20.1, U$1.P$AC5 (DEC3V3)
unnamed: C2-EP-DR.2, D5.2 (A), L5.2, Q3.3 (D)
unnamed: IC9.D1 (SCL), R4.2
unnamed: IC1.D1 (TS/MR), R9.2
unnamed: C2-EP-DR.1, D2.1 (K), D4.2 (A)
unnamed: IC9.E1 (SDA), R2.2
unnamed: EPD_C2.1, J1.4
unnamed: R1_EP_DR.1, R_TYPE_SEL.2, SJ1.2
unnamed: IC3.1 (SDO), R3.2
unnamed: EPD_C6.1, J1.18
unnamed: EPD_C7.1, J1.19
unnamed: EPD_C8.1, J1.20
unnamed: EPD_C1.1, J1.5
unnamed: EPD_C10.1, J1.22
unnamed: EPD_C12.1, J1.24
unnamed: C32.2, IC2.A2 (REG)
unnamed: J4.B5 (CC2), R2_USB.1
unnamed: J4.A5 (CC1), R1_USB.2
OUT+: IC2.A3 (OUT+), TP_OP.TP
OUT-: IC2.C3 (OUT-), TP_ON.TP
P0.00/XL1: C17.2, U$1.P$D2 (P0.00/XL1), X2.1
P0.01/XL2: C18.2, U$1.P$F2 (P0.01/XL2), X2.2
P0.04: U$1.P$J1 (P0.04/AIN2)
P0.09: U$1.P$L24 (P0.09/NFC1)
P0.13/1.5D: C30.2, R5.1, SW_UP.2
P0.13/2.6C: U$1.P$AD8 (P0.13)
P0.14/1.5D: C31.2, R8.1, SW_ENT.2
P0.14/2.7C: U$1.P$AC9 (P0.14)
P0.19: U$1.P$AC15 (P0.19)
P0.20: U$1.P$AD16 (P0.20)
P0.21: U$1.P$AC17 (P0.21)
P0.22: U$1.P$AD18 (P0.22)
P0.23: U$1.P$AC19 (P0.23)
P0.24: U$1.P$AD20 (P0.24)
P0.25: U$1.P$AC21 (P0.25)
P0.26: U$1.P$G1 (P0.26)
P0.27: U$1.P$H2 (P0.27)
P0.28: U$1.P$B11 (P0.28/AIN4)
P0.29: U$1.P$A10 (P0.29/AIN5)
P0.30: U$1.P$B9 (P0.30/AIN6)
P0.31: U$1.P$A8 (P0.31/AIN7)
P1.01/1.6C: Q1.1 (G), R_PWR_EPD.1
P1.01/2.4B: U$1.P$Y23 (P1.01)
P1.02/1.6C: C29.2, R7.1, SW_DN.2
P1.02/2.8C: U$1.P$W24 (P1.02)
P1.03: U$1.P$V23 (P1.03)
P1.04: U$1.P$U24 (P1.04)
P1.05: U$1.P$T23 (P1.05)
P1.06: U$1.P$R24 (P1.06)
P1.07: U$1.P$P23 (P1.07)
P1.09: U$1.P$R1 (P1.09)
P1.10: U$1.P$A20 (P1.10)
P1.11: U$1.P$B19 (P1.11)
P1.12: U$1.P$B17 (P1.12)
P1.13: U$1.P$A16 (P1.13)
P1.14: U$1.P$B15 (P1.14)
P1.15: U$1.P$A14 (P1.15)
PMIC_INT: IC1.A1 (!INT), U$1.P$T2 (P0.11)
PREVGH: D5.1 (K), EPD_C9.1, J1.21
PREVGL: D2.2 (A), EPD_C11.1, J1.23
RESE: J1.3, Q3.2 (S), R1_EP_DR.2
RESET: J2.6, TP_RESET.TP, U$1.P$AC13 (P0.18/RESET)
SCK/1.5B: J1.13
SCK/2.2D: U$1.P$A12 (P0.02/AIN0)
SCL/1.4C: IC2.C1 (SCL), U3.7 (SCL)
SCL/2.4C: IC1.B1 (SCL), IC3.12 (SCX), R4.1, R17.2, TP_SCL.TP, U$1.P$M2 (P0.07)
SDA/1.4C: IC2.B2 (SDA), U3.8 (SDA)
SDA/2.4C: IC1.C1 (SDA), IC3.2 (SDX), R2.1, R18.2, TP_SDA.TP, U$1.P$L1 (P0.06)
SWDCLK: J2.4, TP_SWDCLK.TP, U$1.P$AA24 (SWDCLK)
SWDIO: J2.2, TP_SWDIO.TP, U$1.P$AC24 (SWDIO)
SWO: TP_SWO.TP, U$1.P$AD22 (P1.00)
VBAT/1.2A: C27.2, TP_VBAT.TP, U3.2 (CELL), U3.3 (VDD)
VBAT/2.5C: C37.2, IC1.C2 (BAT)
VBUS/1.5D: C42.1, C43.1, D3.5 (VBUS), J4.A4_B9 (VBUS), J4.A9_B4 (VBUS)
VBUS/2.6D: C21.1, C38.2, IC1.A2 (IN), U$1.P$AD2 (VBUS)
VREG: C23.2, C24.1, C39.1, IC1.B2 (SYS), IC9.A1 (EN), IC9.A2 (VIN_1), IC9.A3 (VIN_2), TP_VREG.TP

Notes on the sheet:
SWD
LiPo Charger
DC/DC
IMU
E-Paper Drive Circuit
E-Paper Display Connector
Haptic Driver
Buttons
Fuel Gauge
USB C Connector & ESD Protection
MCU, Power, IMU, SWD
drawn by: Andreea Fuior
E-Paper & Peripherals
1/2
2/2
N.C.

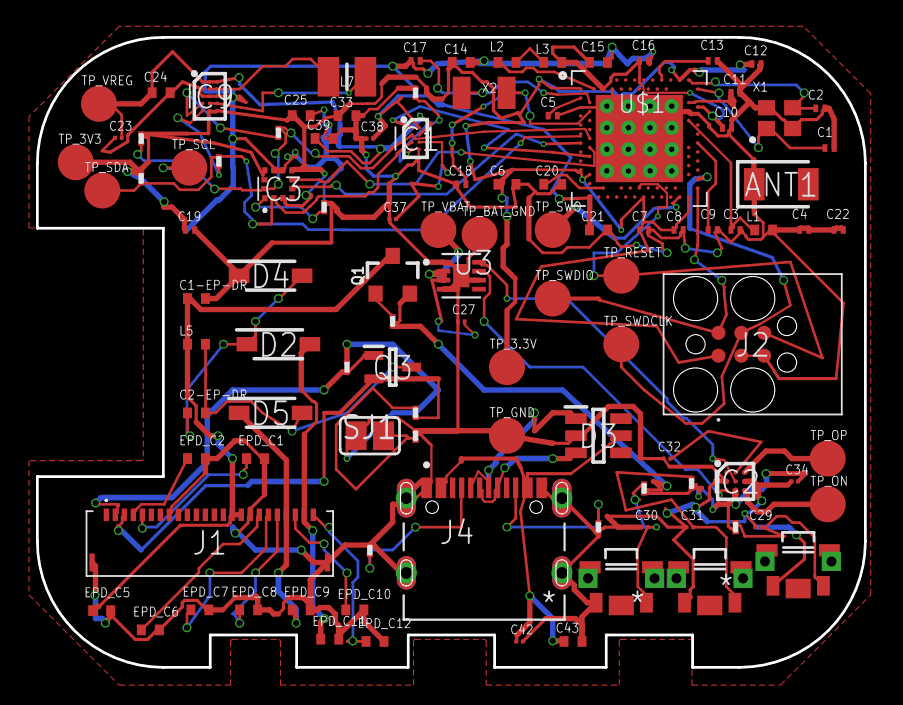
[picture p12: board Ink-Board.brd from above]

Board: 2 copper layers, 46.0 x 35.0 mm, 105 parts (0 on the bottom side), 64 nets.

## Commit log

2026-04-10 First steps of the project
    [Ink-Board.brd, Ink-Schematic.sch]
2026-04-22 Updating the project
    [Ink-Board.brd, Ink-Schematic.sch, SmartWatch.bom.csv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]

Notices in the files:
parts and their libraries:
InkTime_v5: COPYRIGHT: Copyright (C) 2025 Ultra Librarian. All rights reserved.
